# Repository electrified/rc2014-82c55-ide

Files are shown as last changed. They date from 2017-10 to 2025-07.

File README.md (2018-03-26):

# 82c55 based IDE interface for the RC2014 computer

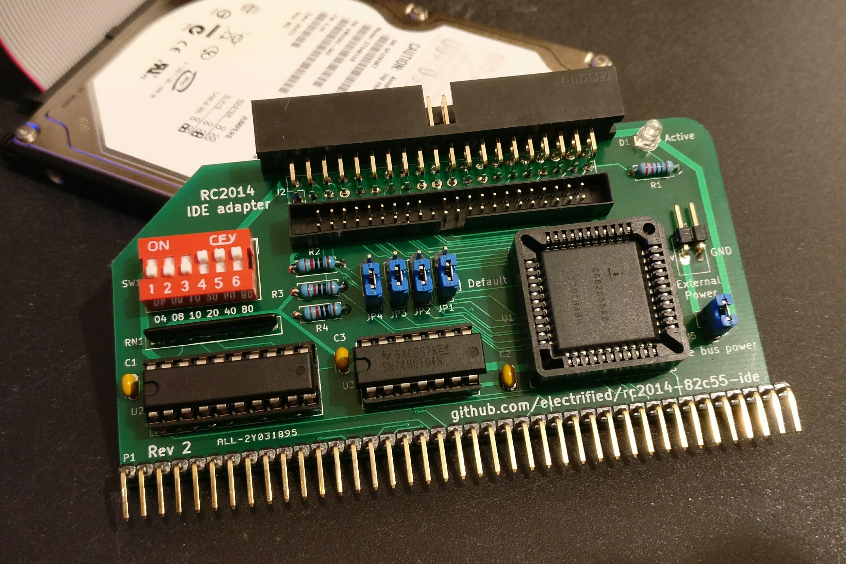
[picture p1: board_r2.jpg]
Picture of the board


## The board
This is a 82c55 based IDE interface for the RC2014 Z80 8-bit computer. IDE uses a 16 bit data bus, so a parallel interface IC is needed to connect one to an 8 bit computer.
This adapter uses the same pin mapping as the ECB Disk IO v3 and the design is heavily based on that. (https://www.retrobrewcomputers.org/lib/exe/fetch.php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)

## What can you use this for?

* Connecting an IDE hard drive to your RC2014 and using it in RomWBW, CP/M-IDE or in C programs built with z88dk.

## Features

* 40 pin IDE for normal 3.5" hard drives
* 44 pin IDE header for 2.5" laptop hard drives
* Pins for supplying external 5v for the laptop HD if necessary
* IO port selectable via DIP switch

## Getting started with RomWBW
Wayne Warthen has incorporated support for the RC2014 into [mainline RomWBW](https://github.com/wwarthen/RomWBW). Using this is preferred to Scott Baker's fork as there have been various improvements since Scott forked off. Support for the IDE adapter can be enabled by setting the following in your configuration and rebuilding:

```
PPIDEENABLE     .EQU    TRUE
```

Read the RomWBW readme (`Source/ReadMe.txt`) if you are unfamiliar with the configuration and build process.

The other settings have already been set to the appropriate values in `Source/HBIOS/cfg_rc.asm`, so all is required is to enable PPIDE.

The board I/O address should be set to 0x20; set the A5 switch "on" and all the others off.

## Getting started with z88dk
Support has only recently landed so you'll need a very recent pull of z88dk.
The 82c55 driver, IDE layer and DiskIO are only present within z88dk's RC2014 newlib target. (Not the classic library). 

Phillip Stevens has packaged ChaN's FatFS as a z88dk library, this can be used with above z88dk IDE driver to write programs that can access FAT filesystems.

See https://github.com/feilipu/z88dk-libraries/tree/master/ff and the programs in the example directory.

## CP/M - IDE
Phillip Stevens has made a CP/M version where the CP/M disk images can reside on a FAT filesystem. This requires only a minimal RC2014 setup. See [the GitHub repository](https://github.com/RC2014Z80/RC2014/tree/master/ROMs/CPM-IDE) and [Google groups thread](https://groups.google.com/forum/#!topic/rc2014-z80/V07eugtGFZo) for more details.

## Jumpers and switches
Pin 1 is identified by having square pad.

### SW1
IO address of the board. For operation at 0x20 as RomWBW expects, set the switch marked A5 / 20 to on and all the others to off.

### JP1 - JP4
Described on the back of the board. Some of the pins in the 82c55 C port have a special purpose if you are using the board in mode 2, for something other than being an IDE adapter. Usually the defaults of pins 2-3 are correct.

### JP5
Use external power from J1. Rev 2 of the board only has 2 pins, jumper for bus power.

pins|description
----|------------
1-2 | Bus power
2-3 | External power

## Outputs

* J2 - 40 pin IDE
* J3 - 44 pin IDE

## Bill Of Materials

Reference| Value|Rapid part no|RS part no|Digi-key part no|
---------|------|-------------|----------|----------------|
P1|1x39 right angled pin header|||732-5350-ND|
U1|CS82C55AZ (PLCC version)||921-5567|CS82C55AZ-ND|
U1|PLCC44 socket|22-0350||AE10057-ND|
U3|74HCT04 (DIP)|||296-1605-5-ND|
J2|2x20 shrouded right angled pin header|19-0047||732-5401-ND|
D1|LED of your choosing ;)|||160-1130-ND|
R1|270R through hole resistor (or value suitable for chosen LED)|||CF14JT270RCT-ND|
U2|74HCT688 (DIP)|||296-2131-5-ND|
RN1|10K commoned SIP resistor array (7 resistors, 8 pin)|63-0125||4608X-1-103LF-ND|
C1|0.1uF ceramic capacitor|||BC2665CT-ND|
C2|0.1uF ceramic capacitor|||BC2665CT-ND|
C3|0.1uF ceramic capacitor|||BC2665CT-ND|
J3|2.5" IDE connector 2x22 Shrouded 2mm pitch connector|||WM18567-ND|
SW1|6 switch DIP switch|80-0338||CT2066-ND|
J5|1x02 pin header straight, 2.54mm pitch|||732-5315-ND|
J1|1x02 pin header straight, 2.54mm pitch|||732-5315-ND|
JP1|1x03 pin header straight, 2.54mm pitch|||732-5316-ND|
JP2|1x03 pin header straight, 2.54mm pitch|||732-5316-ND|
JP3|1x03 pin header straight, 2.54mm pitch|||732-5316-ND|
JP4|1x03 pin header straight, 2.54mm pitch|||732-5316-ND|
R3|10K through hole resistor|||CF14JT10K0CT-ND|
R4|10K through hole resistor|||CF14JT10K0CT-ND|
R2|10K through hole resistor|||CF14JT10K0CT-ND|
||Jumpers|||952-2882-ND|

## Construction tips
* Pin 20 of both the 40 pin and 44 pin IDE connector is usually missing as a "key" and is blocked off on many cables. It's best to remove pin 20 from both connectors before soldering them.
* If you're using a 2.5" and powering it from the bus, ensure you have a sufficient power supply. As an example, my 2.5" Seagate Momentum drive is specced to pull up to 2.5A on startup
* If you are using the board as an IDE controller, keep the JP1-4 in their default position of 2-3
* The cutout on the boxed IDE connectors should be towards the RC2014 bus connector in the case of the 44 pin connector, and facing the user in the case of the 40 pin connector.

## Compatibility
The IDE board will not work if the Digital IO v1.0 board is present in your RC2014. This is due to the IO board having very loose addressing - it responds on any IO address below 128 ending with binary 00, 01 or 10. This results in it conflicitng with the IDE adapter.

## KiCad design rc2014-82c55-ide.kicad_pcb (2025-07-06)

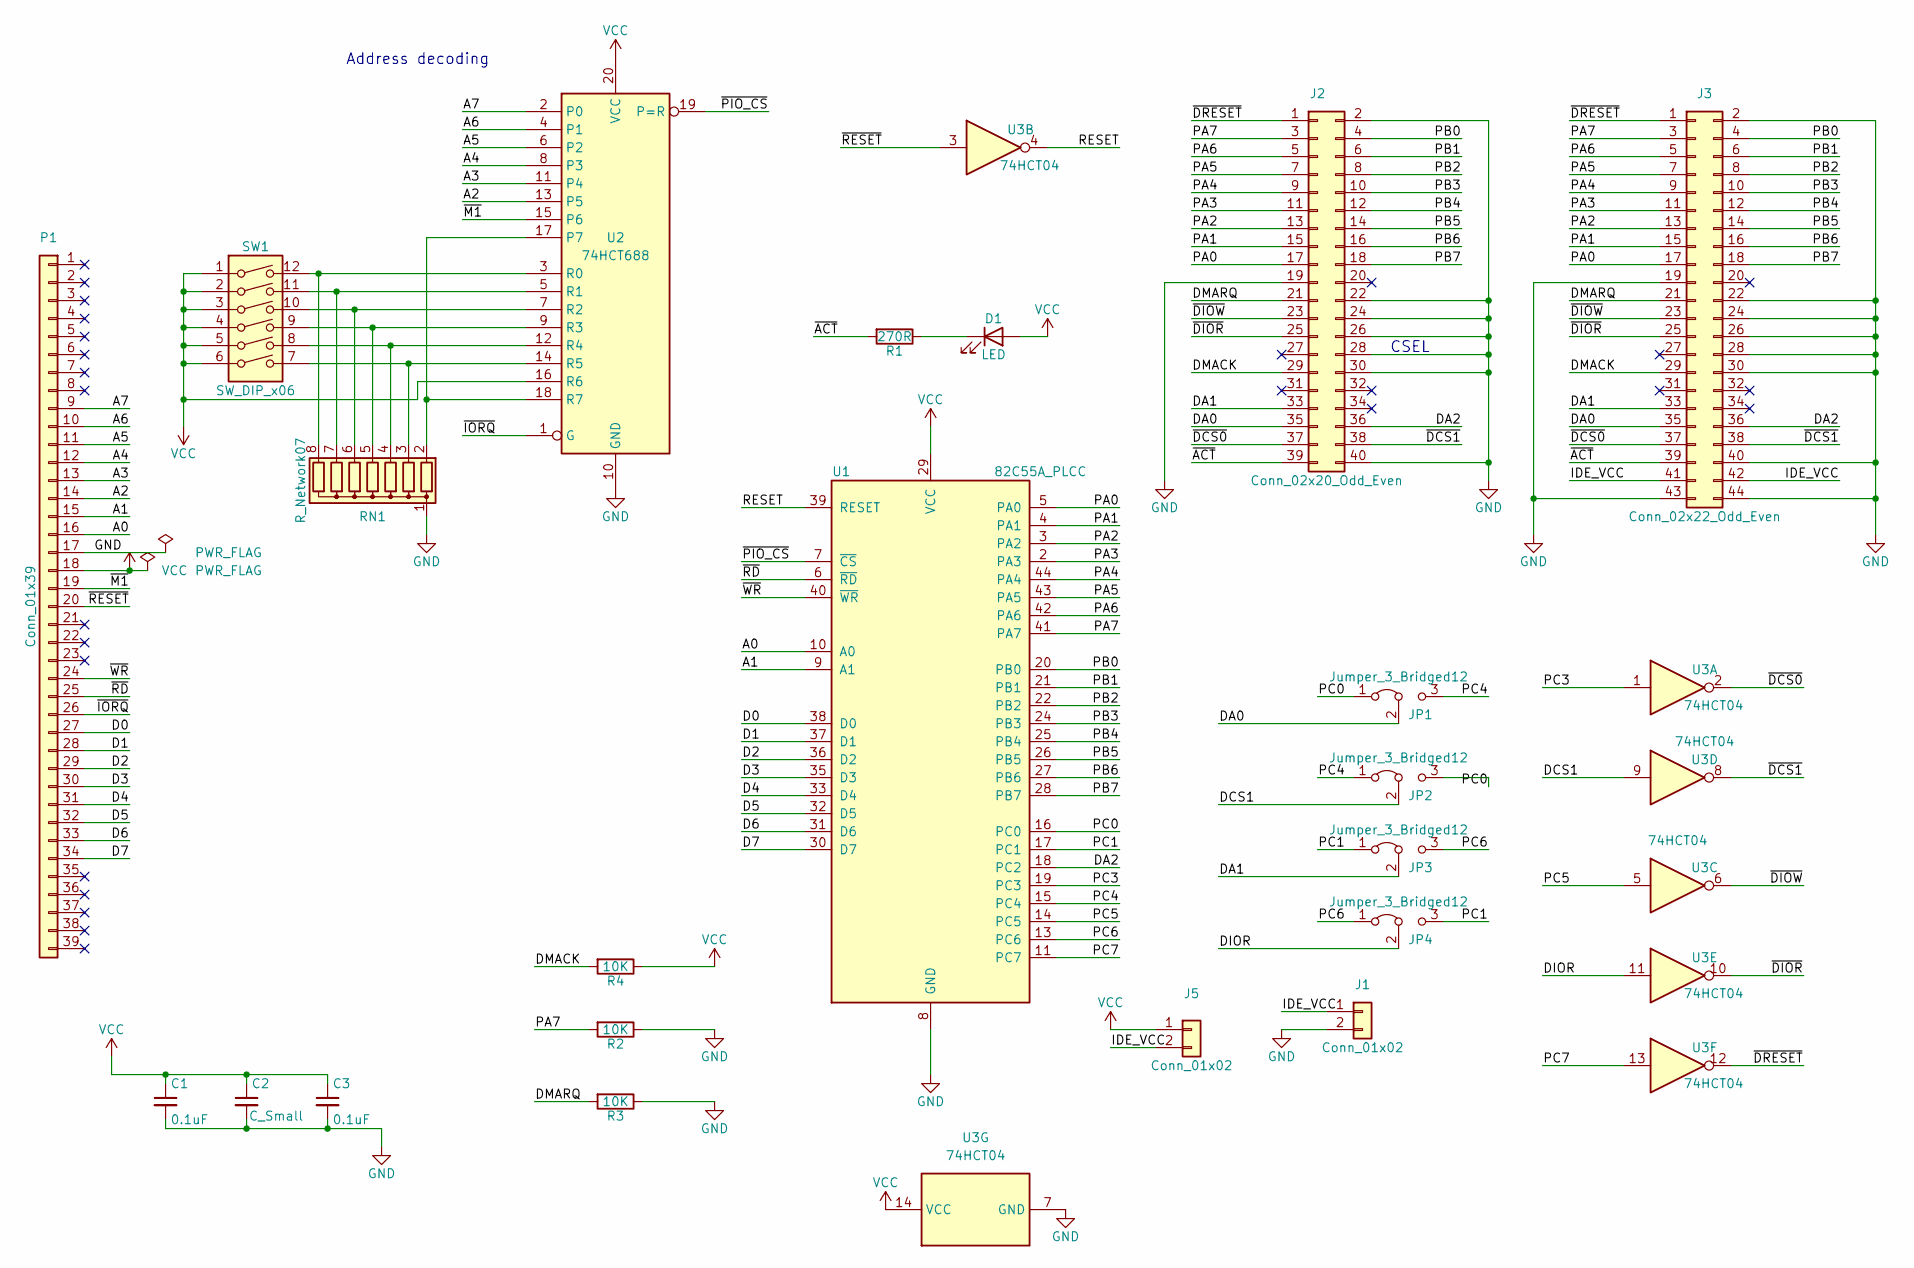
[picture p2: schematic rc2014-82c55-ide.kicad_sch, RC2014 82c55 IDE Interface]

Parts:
C1, C3: 0.1uF; C_Disc_D3.0mm_W2.0mm_P2.50mm
C2: C_Small; C_Disc_D3.0mm_W2.0mm_P2.50mm
D1: LED; LED_D3.0mm
J1, J5: Conn_01x02; PinHeader_1x02_P2.54mm_Vertical
J2: Conn_02x20_Odd_Even; PinHeader_2x20_P2.54mm_Vertical
J3: Conn_02x22_Odd_Even; PinHeader_2x22_P2.00mm_Vertical
JP1, JP2, JP3, JP4: Jumper_3_Bridged12; PinHeader_1x03_P2.54mm_Vertical
P1: Conn_01x39; Pin_Header_Straight_1x39_Pitch2.54mm_NoSilk
R1: 270R; R_Axial_DIN0207_L6.3mm_D2.5mm_P7.62mm_Horizontal
R2, R3, R4: 10K; R_Axial_DIN0207_L6.3mm_D2.5mm_P7.62mm_Horizontal
RN1: R_Network07; R_Array_SIP8
SW1: SW_DIP_x06; SW_DIP_SPSTx06_Slide_9.78x17.42mm_W7.62mm_P2.54mm
U1: 82C55A_PLCC; PLCC-44_THT-Socket
U2: 74HCT688; DIP-20_W7.62mm_Socket_LongPads
U3: 74HCT04; DIP-14_W7.62mm_Socket_LongPads

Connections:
/A0: P1.16, U1.10 (A0)
/A1: P1.15, U1.9 (A1)
/A2: P1.14, U2.13 (P5)
/A3: P1.13, U2.11 (P4)
/A4: P1.12, U2.8 (P3)
/A5: P1.11, U2.6 (P2)
/A6: P1.10, U2.4 (P1)
/A7: P1.9, U2.2 (P0)
/D0: P1.27, U1.38 (D0)
/D1: P1.28, U1.37 (D1)
/D2: P1.29, U1.36 (D2)
/D3: P1.30, U1.35 (D3)
/D4: P1.31, U1.33 (D4)
/D5: P1.32, U1.32 (D5)
/D6: P1.33, U1.31 (D6)
/D7: P1.34, U1.30 (D7)
/DA0: J2.35, J3.35, JP1.2 (C)
/DA1: J2.33, J3.33, JP3.2 (C)
/DA2: J2.36, J3.36, U1.18 (PC2)
/DCS1: JP2.2 (C), U3.9
/DIOR: JP4.2 (C), U3.11
/DMACK: J2.29, J3.29, R4.2
/DMARQ: J2.21, J3.21, R3.2
/IDE_VCC: J1.1, J3.41, J3.42, J5.2
/PA0: J2.17, J3.17, U1.5 (PA0)
/PA1: J2.15, J3.15, U1.4 (PA1)
/PA2: J2.13, J3.13, U1.3 (PA2)
/PA3: J2.11, J3.11, U1.2 (PA3)
/PA4: J2.9, J3.9, U1.44 (PA4)
/PA5: J2.7, J3.7, U1.43 (PA5)
/PA6: J2.5, J3.5, U1.42 (PA6)
/PA7: J2.3, J3.3, R2.2, U1.41 (PA7)
/PB0: J2.4, J3.4, U1.20 (PB0)
/PB1: J2.6, J3.6, U1.21 (PB1)
/PB2: J2.8, J3.8, U1.22 (PB2)
/PB3: J2.10, J3.10, U1.24 (PB3)
/PB4: J2.12, J3.12, U1.25 (PB4)
/PB5: J2.14, J3.14, U1.26 (PB5)
/PB6: J2.16, J3.16, U1.27 (PB6)
/PB7: J2.18, J3.18, U1.28 (PB7)
/PC0: JP1.1 (A), JP2.3 (B), U1.16 (PC0)
/PC1: JP3.1 (A), JP4.3 (B), U1.17 (PC1)
/PC3: U1.19 (PC3), U3.1
/PC4: JP1.3 (B), JP2.1 (A), U1.15 (PC4)
/PC5: U1.14 (PC5), U3.5
/PC6: JP3.3 (B), JP4.1 (A), U1.13 (PC6)
/PC7: U1.11 (PC7), U3.13
/RESET: U1.39 (RESET), U3.4
/~ACT: J2.39, J3.39, R1.2
/~DCS0: J2.37, J3.37, U3.2
/~DCS1: J2.38, J3.38, U3.8
/~DIOR: J2.25, J3.25, U3.10
/~DIOW: J2.23, J3.23, U3.6
/~DRESET: J2.1, J3.1, U3.12
/~IORQ: P1.26, U2.1 (G)
/~M1: P1.19, U2.15 (P6)
/~PIO_CS: U1.7 (~CS), U2.19 (P=R)
/~RD: P1.25, U1.6 (~RD)
/~RESET: P1.20, U3.3
/~WR: P1.24, U1.40 (~WR)
GND: C1.2, C2.2, C3.2, J1.2, J2.2, J2.19, J2.22, J2.24, J2.26, J2.28, J2.30, J2.40, J3.2, J3.19, J3.22, J3.24, J3.26, J3.28, J3.30, J3.40, J3.43, J3.44, P1.17, R2.1, R3.1, RN1.1 (common), U1.8 (GND), U2.10 (GND), U3.7 (GND)
unnamed: D1.1 (K), R1.1
unnamed: RN1.2 (R1), U2.17 (P7), U2.18 (R7)
unnamed: RN1.3 (R2), SW1.7, U2.14 (R5)
unnamed: RN1.4 (R3), SW1.8, U2.12 (R4)
unnamed: RN1.5 (R4), SW1.9, U2.9 (R3)
unnamed: RN1.6 (R5), SW1.10, U2.7 (R2)
unnamed: RN1.7 (R6), SW1.11, U2.5 (R1)
unnamed: RN1.8 (R7), SW1.12, U2.3 (R0)
VCC: C1.1, C2.1, C3.1, D1.2 (A), J5.1, P1.18, R4.1, SW1.1, SW1.2, SW1.3, SW1.4, SW1.5, SW1.6, U1.29 (VCC), U2.16 (R6), U2.20 (VCC), U3.14 (VCC)

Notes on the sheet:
CSEL
Address decoding

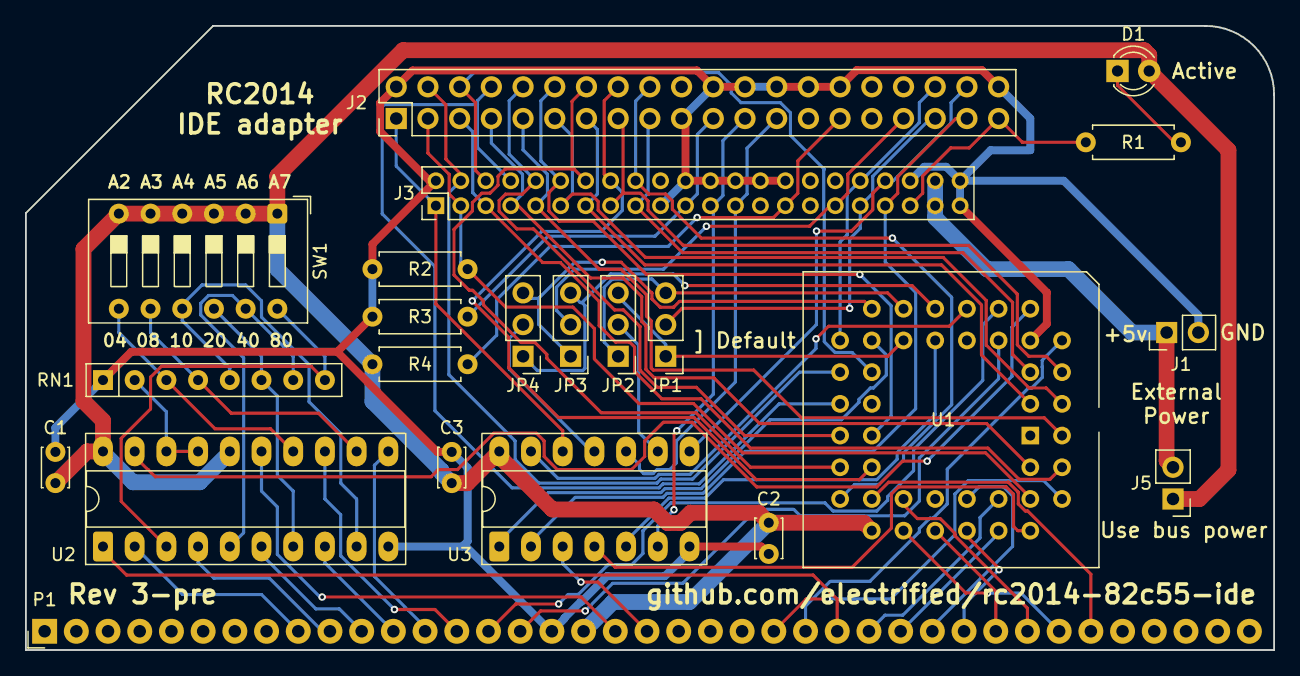
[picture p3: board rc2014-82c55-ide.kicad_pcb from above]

Board: 2 copper layers, 100.0 x 50.0 mm, 22 parts (0 on the bottom side), 70 nets.

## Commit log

2017-09-22 Add jumpers
    [rc2014-82c55-ide.sch]
2017-09-22 add rtc
    [rc2014-82c55-ide.sch]
2017-09-24 remove clock
    [rc2014-82c55-ide.sch]
2017-09-26 R1 as submitted to allpcb
    [rc2014-82c55-ide.kicad_pcb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]
2017-10-01 Update title on pages
    [rc2014-82c55-ide.kicad_pcb, rc2014-82c55-ide.sch]
2017-10-17 add picture of the board
2017-10-18 r2 as sent for manufacturing
    [rc2014-82c55-ide.kicad_pcb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]
2017-10-24 update readme and board pic
2022-03-08 Migration to KiCAD 6 WIP
    [rc2014-82c55-ide.kicad_pcb, rc2014-82c55-ide.sch]
2022-03-08 aisler drc updates
    [rc2014-82c55-ide.kicad_pcb, rc2014-82c55-ide.kicad_sch]
2022-03-09 Don't update to asler DRC rules
    [rc2014-82c55-ide.kicad_pcb]
2022-03-09 Further kicad 6 migration
    [rc2014-82c55-ide.kicad_pcb, rc2014-82c55-ide.kicad_sch]
2022-03-09 Remove unused footprints
    [rc2014-82c55-ide.kicad_pcb]
2022-07-25 Regenerate gerbers
    [rc2014-82c55-ide-B_Cu.gbr, rc2014-82c55-ide-B_Mask.gbr, rc2014-82c55-ide-B_Silkscreen.gbr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]
2022-10-17 Update PCB components
    [rc2014-82c55-ide.kicad_pcb]
2025-07-06 update to kicad 9
    [rc2014-82c55-ide.kicad_pcb, rc2014-82c55-ide.kicad_sch]
